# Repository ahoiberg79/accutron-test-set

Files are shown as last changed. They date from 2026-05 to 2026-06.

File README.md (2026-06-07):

# Accutron Test Set

Modern digital bench supply and current meter for Bulova Accutron tuning fork movements.

Designed for:

- voltage phasing
- low-amplitude testing
- current diagnostics
- general tuning fork movement evaluation

---

## Features

Adjustable low-voltage output with real-time voltage and microamp display.

Built around:

- Arduino Nano
- ADS1115 16-bit ADC
- SSD1306 OLED
- LM4040 precision reference

USB powered for bench use.

---

## Functions

### Adjustable Output Voltage

```text
0.00V → 2.50V
```

Common Accutron phasing voltages:

```text
1.05V
1.35V
1.55V
1.75V
1.80V
```

---

### Microamp Measurement

Current is measured through a 1k precision sense resistor using ADS1115 measurement across the sense resistor.

```text
A1 = sense high
A0 = sense low

Current = (A1 - A0) / 1000Ω
```

Displayed in real time on the OLED in microamps.

The measured current represents the current flowing through the connected watch movement, not the total current drawn by the tester circuitry.

---

### Actual Terminal Voltage Measurement

PCB V1.6 measures actual output terminal voltage directly at OUTPUT+ using ADS1115 channel A2.

```text
OUTPUT+ → ADS1115 A2
```

The displayed voltage is therefore the actual watch terminal voltage.

Firmware no longer applies software correction for the 470Ω output protection resistor.

Previous method:

```text
terminal voltage = set voltage - calculated 470Ω drop
```

Current PCB V1.6 method:

```text
terminal voltage = A2 voltage reading
```

---

## Hardware

### Main Components

```text
Arduino Nano
ADS1115 ADC Module
SSD1306 OLED Display
LM4040AIZ-2.5 precision reference
10-turn 10k potentiometer
SPST RUN/STOP switch
```

### Passive Components

```text
1k precision sense resistor
470Ω output protection resistor
100k switched-node pull-down resistor
2.2k LM4040 bias resistor
10µF capacitors
0.1µF capacitors
```

---

## Analog Measurement Path

```text
LM4040 2.5V reference
↓
10-turn 10k potentiometer
↓
RUN/STOP switch
↓
A1 / sense high
↓
1k current sense resistor
↓
A0 / sense low
↓
470Ω output protection resistor
↓
OUTPUT+
↓
watch movement
↓
GND
```

Voltage sense:

```text
OUTPUT+ → ADS1115 A2
```

---

## Switched-Node Pull-Down Resistor

PCB V1.6 includes a required 100kΩ pull-down resistor from the RUN/STOP switch output node to ground.

Connection:

```text
SW_OUT / ADS1115 A1 / high side of 1k current-sense resistor
↓
100kΩ
↓
GND
```

When the RUN/STOP switch is open, the switched output chain is otherwise floating:

```text
A1 → 1k sense resistor → A0 → 470Ω protection resistor → OUTPUT+ / ADS1115 A2
```

With no DC reference, this high-impedance node can retain charge or pick up leakage and capacitive coupling from the USB supply, wiring, ADS1115 inputs, display wiring, or nearby circuitry. This can cause false OFF-state voltage readings at OUTPUT+ / A2.

The 100kΩ pull-down provides a weak ground reference and discharge path for the switched node, forcing the output chain near 0V in STOP mode.

The resistor is intentionally placed at the switch output / A1 node, before the 1k current-sense resistor. Its current returns directly to ground and does not pass through the 1k sense resistor, so it is not included in the displayed watch-current measurement.

Do not place this resistor from OUTPUT+ to ground. A resistor at OUTPUT+ would draw current through the 1k sense resistor and would appear as false watch current.

Example:

```text
1.5V / 100kΩ = 15µA
```

If placed at OUTPUT+, that 15µA would be incorrectly displayed as watch current.

---

## Display Behavior

The OLED displays:

```text
terminal voltage
watch current in µA
```

During voltage adjustment, current display is temporarily blanked:

```text
--.- uA
```

After the voltage settles, the firmware discards transient readings and resumes displaying measured current.

This prevents stale or adjustment-related current readings from being shown as valid watch current.

---

## Notes

This is a bench-powered device intended for hobbyist restoration and diagnostic use.

The design is inspired by original Bulova test equipment but implemented using modern components and digital measurement.

The current display is intended to mimic the useful behavior of an analog microamp meter while preserving a true measured current value from the 1k sense resistor.

3D Printed Potentiometer Knob I used can be found here: https://makerworld.com/en/models/1847807-25mm-potentiometer-knob-mxr-fender-style-6-35mm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

3D Printed 0.96 OLED Panel Mount I used can be found here: https://www.printables.com/model/569276-ssd1306-adapter-for-enclosure-mounting/files

3D Printed enclosure I designed can be found here: https://makerworld.com/en/models/2901741-modern-accutron-test-set-enclosure#profileId-3243880

---

## Future Development

Possible future improvements:

```text
Larger OLED
Digital voltage presets
PCB version
Selectable movement profiles
High-current caution indicator
Kelvin terminal sensing
Rechargeable battery operation
Dedicated movement adapters
```

---

## Usage & Licensing

This project is shared for:

- personal use
- learning
- hobbyist restoration work

Please do not commercially reproduce or sell this design or derivative versions without permission from the project author.

Community improvements and technical collaboration are encouraged.

---

## Disclaimer

Use at your own risk when testing vintage electronic watch movements.

Always verify polarity and voltage before connecting a movement.

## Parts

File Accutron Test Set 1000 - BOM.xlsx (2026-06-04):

Category | Qty per unit | Item | Spec / Value | PCB Ref / Use | Buy / Track Notes | Vendor
PCB | 1 | Custom PCB | 2-layer FR-4 approx 80x60mm | Main board | Include PCB shipping divided by quantity | PCBWay
Controller | 1 | Arduino Nano V3 | ATmega328P USB-C preferred | U1 | Socketed | Amazon
ADC | 1 | ADS1115 module | 16-bit I2C ADC 1x10 header | U2 | Socketed | Amazon
Voltage Reference | 1 | LM4040AIZ-2.5/NOPB | 2.5V shunt reference TO-92 | U3 | LM4040BIZ also acceptable | Mouser
Potentiometer | 1 | 10-turn potentiometer | 10k linear panel mount solder lugs | RV1 | Voltage control | Jameco
Display | 1 | SSD1306 OLED module | 0.96 inch I2C 4-pin | DS1 | Panel mounted | Amazon
Switch | 1 | SPST rocker switch | ON/OFF panel mount | SW1 | RUN / STOP | Amazon
Output Jack | 1 | Red banana jack / binding post | 4mm panel mount | J1 | Output positive / SENSE_VOLTAGE | Amazon
Output Jack | 1 | Black banana jack / binding post | 4mm panel mount | J2 | Output negative / GND | Amazon
Test leads | 1 | Black/red banana & alligator clips | Found cheap ones on Jameco | J1 & J2 output | Plugs into J1 and J2 | Jameco
USB Power | 1 | Panel-mount USB-C extension | USB-C female panel / usb-c male | Nano USB input | Plugs into Nano USB-C | AliExpress
Resistor | 1 | Metal film resistor | 2.2k | R1 | LM4040 feed resistor | Amazon
Resistor | 1 | Precision metal film resistor | 1k 0.1% or 1% | R2 | Current sense resistor | Amazon
Resistor | 1 | Metal film resistor | 470R | R3 | Output protection resistor | Amazon
Resistor | 1 | Metal film resistor | 100k | R4 | Output pull-down resistor | Amazon
Capacitor | 2 | Electrolytic capacitor | 10uF radial | C1 C3 | Observe polarity | Amazon
Capacitor | 4 | Ceramic capacitor | 0.1uF | C2 C4 C5 C6 | Bypass capacitors | Amazon
Header Socket | 2 | Female header strip | 1x15 2.54mm | U1 socket | For Arduino Nano | Amazon
Header Socket | 1 | Female header strip | 1x10 2.54mm | U2 socket | For ADS1115 module | Amazon
Header / Connector | 1 | 4-pin header or connector | 2.54mm or JST | DS1 | OLED connection | Amazon
Header / Connector | 1 | 3-pin header or connector | 2.54mm or JST | RV1 | Pot connection | Amazon
Header / Connector | 1 | 2-pin header or connector | 2.54mm or JST | SW1 | Switch connection | Amazon
Wire Pad / Connector | 1 | 1-pin wire pad or header | Output positive | J1 | Wire to red banana jack | Amazon
Wire Pad / Connector | 1 | 1-pin wire pad or header | Output negative | J2 | Wire to black banana jack | Amazon
Knob | 1 | Potentiometer knob | Fits pot shaft | RV1 | Optional counting dial if desired | Jameco
Enclosure | 1 | 3D printed enclosure | Custom | Case | Include filament/resin cost | Local
PCB Holder | 1 | 3D printed PCB holder | M2 mounting pattern | Board holder | Include filament/resin cost | Local
Consumable | 1 | Wire/solder/heat shrink/nuts/screws | All inclusive | Assembly | All consumable parts | Local

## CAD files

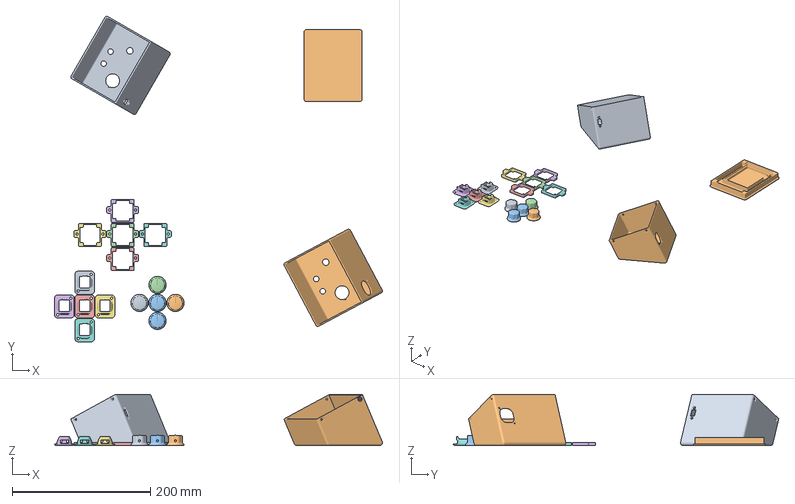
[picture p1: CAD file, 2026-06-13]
Full Accutron Test Set Print Parts.3mf
474.8 x 471.3 x 74.1 mm
Top
Base.stl
25mm MXR Knob T Lab v2.stl x 5
Printed XLR Keystone.step x 5
Top.stl

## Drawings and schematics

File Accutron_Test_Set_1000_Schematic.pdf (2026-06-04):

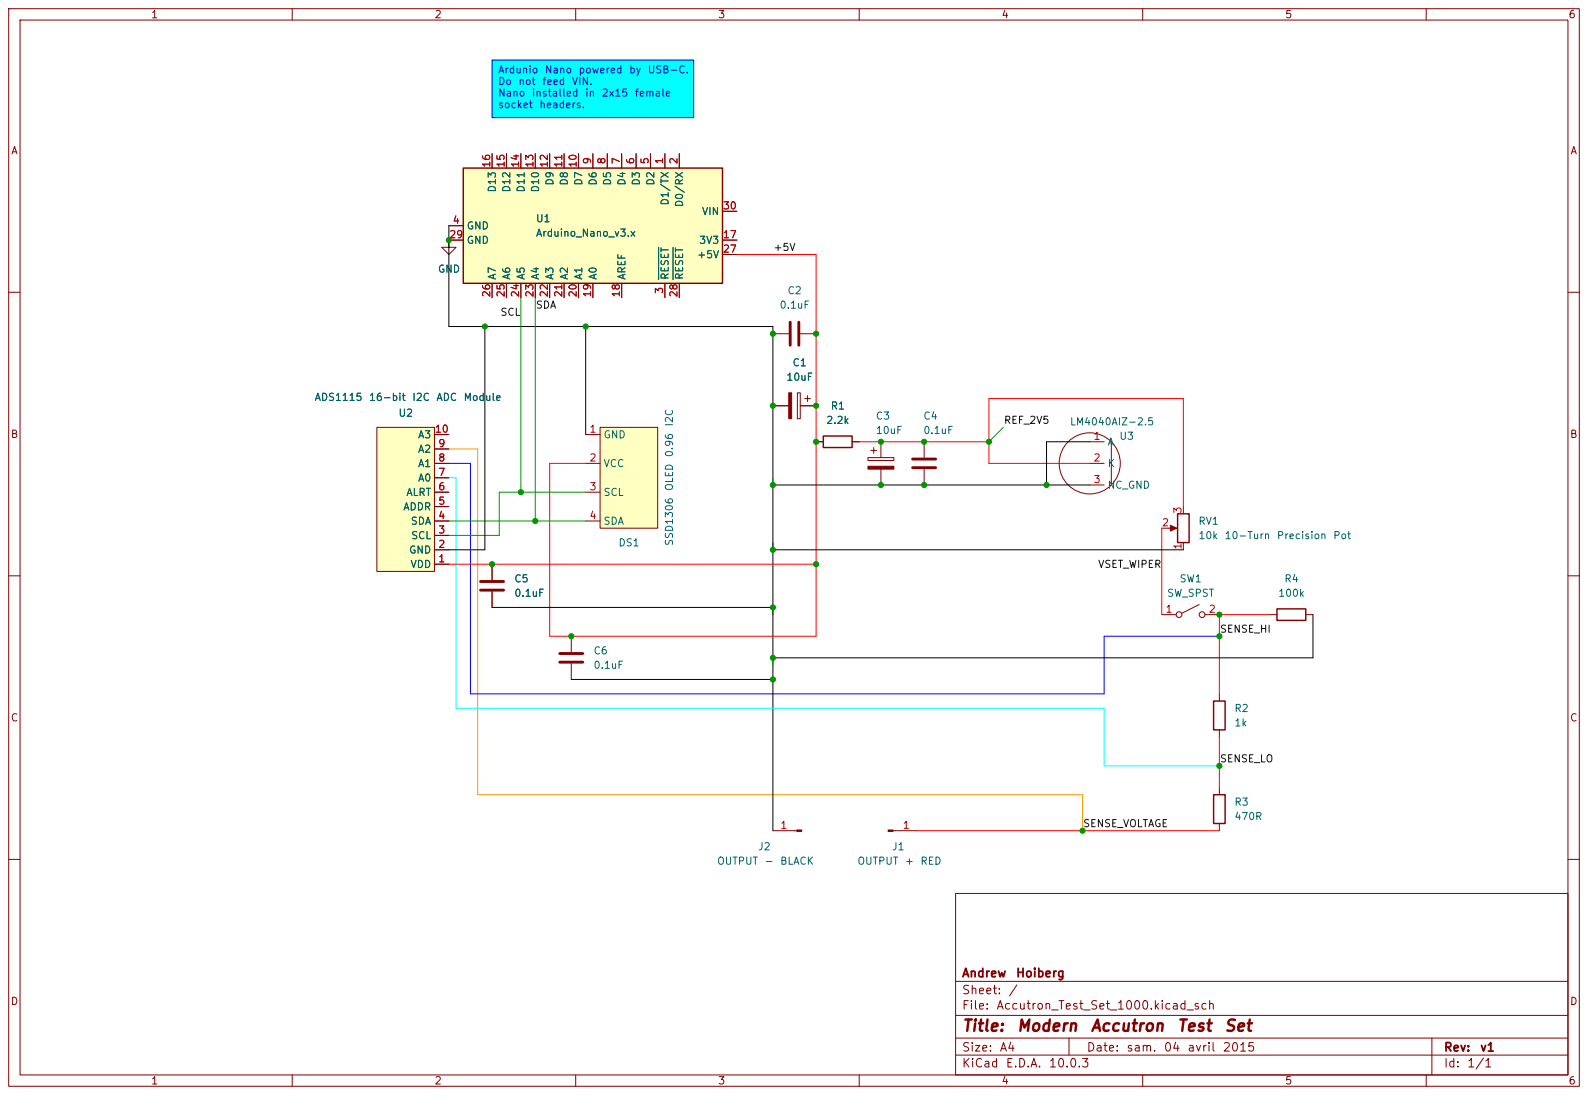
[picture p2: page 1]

Ardunio Nano powered by USB-C. Do not feed VIN. Nano installed in 2x15 female

Andrew Hoiberg
Sheet: /
File: Accutron_Test_Set_1000.kicad_sch
Title: Modern Accutron Test Set

Size: A4 | Rev: v1
KiCad E.D.A. 10.0.3 | Id: 1/1

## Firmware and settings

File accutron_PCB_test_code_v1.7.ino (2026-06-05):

#include <Wire.h>
#include <Adafruit_GFX.h>
#include <Adafruit_SSD1306.h>
#include <Adafruit_ADS1X15.h>

#define SCREEN_WIDTH 128
#define SCREEN_HEIGHT 64

Adafruit_SSD1306 display(SCREEN_WIDTH, SCREEN_HEIGHT, &Wire, -1);
Adafruit_ADS1115 ads;

// PCB V1.6 ADS1115 channel mapping
const uint8_t CH_SENSE_LO = 0;  // A0: after 1k sense resistor
const uint8_t CH_SENSE_HI = 1;  // A1: before 1k sense resistor
const uint8_t CH_OUTPUT   = 2;  // A2: actual output terminal voltage

// Hardware values
const float senseResistor_ohms = 1000.0;

// ADS1115 GAIN_ONE = +/-4.096V range = 0.125mV per count
const float ADS_VOLTS_PER_COUNT = 0.000125;

// -----------------------------
// Current measurement settings
// -----------------------------

// Paired A1/A0 samples per current block.
// Higher = more stable but slower response.
const int currentBlockSamples = 32;

// Current rolling average buffer.
// Higher = more analog-meter-like damping.
const int currentBufferSize = 8;

float currentBuffer[currentBufferSize];
int currentBufferIndex = 0;
int currentBufferCount = 0;

// Final display damping after rolling average.
// Lower = steadier/slower. Higher = faster/jumpier.
const float currentDisplaySmoothing = 0.12;

float displayedCurrent_uA = 0.0;
float filteredCurrent_uA = 0.0;

// Noise cleanup
const float zeroDeadband_uA = 0.35;

// If a single current block jumps this much, require persistence.
// This prevents one bad block from moving the display hard.
const float currentJumpThreshold_uA = 5.0;
const int requiredJumpPersistence = 3;
int jumpPersistenceCounter = 0;
float pendingJumpCurrent_uA = 0.0;

// Neutral caution flag only.
// Tester does not know movement type, so this should not be treated as pass/fail.
const float highCurrentThreshold_uA = 12.0;
const int highCurrentPersistenceBlocks = 4;
int highCurrentCounter = 0;
bool highCurrentFlag = false;

// -----------------------------
// Voltage / adjustment blanking
// -----------------------------

// Larger threshold prevents normal phasing drift from being treated as pot movement.
const float voltageMoveThreshold = 0.025;       // 25mV
const int voltageMoveConfirmCount = 3;          // require repeated movement
const unsigned long currentReacquire_ms = 500;  // blank after confirmed adjustment

// Below this, output is considered STOP/OFF.
// Current readings at near-zero output voltage are not meaningful.
const float outputOffThreshold_V = 0.10;

float previousVoltage = 0.0;
float stableVoltageReference = 0.0;
int voltageMoveCounter = 0;

unsigned long lastVoltageMove_ms = 0;
bool currentDisplayValid = false;

// -----------------------------
// Function declarations
// -----------------------------

float readOutputVoltage();
float readCurrentBlock_uA();
void resetCurrentFilter(float seedCurrent_uA);
void clearCurrentFilter();
float averageCurrentBuffer();
float processCurrentForDisplay(float rawCurrent_uA);
void updateHighCurrentFlag(float rawCurrent_uA);
void drawDisplay(float terminalVoltage, float current_uA, bool showCurrent);
void printDebug(float vOutput, float rawCurrent_uA, float filteredCurrent_uA, bool showCurrent);

// -----------------------------
// Setup
// -----------------------------

void setup() {
  Serial.begin(115200);

  if (!display.begin(SSD1306_SWITCHCAPVCC, 0x3C)) {
    while (true);
  }

  display.clearDisplay();
  display.setTextColor(SSD1306_WHITE);

  if (!ads.begin()) {
    display.setTextSize(1);
    display.setCursor(0, 0);
    display.println("ADS1115 FAIL");
    display.display();
    while (true);
  }

  ads.setGain(GAIN_ONE);

  stableVoltageReference = 0.0;
  previousVoltage = 0.0;
  lastVoltageMove_ms = millis();

  display.clearDisplay();
  display.display();
}

// -----------------------------
// Main loop
// -----------------------------

void loop() {
  // 1. Read actual output terminal voltage from A2.
  float terminalVoltage = readOutputVoltage();

  // 2. Treat very low output as STOP/OFF.
  bool outputOff = terminalVoltage < outputOffThreshold_V;

  if (outputOff) {
    // In STOP/OFF, current display is intentionally blanked.
    // Any current reading here is not useful watch-current information.
    lastVoltageMove_ms = millis();
    currentDisplayValid = false;
    clearCurrentFilter();

    stableVoltageReference = terminalVoltage;
    voltageMoveCounter = 0;
  } else {
    // 3. Detect deliberate voltage movement without reacting to small drift.
    float voltageChangeFromStable = fabs(terminalVoltage - stableVoltageReference);

    if (voltageChangeFromStable > voltageMoveThreshold) {
      voltageMoveCounter++;

      if (voltageMoveCounter >= voltageMoveConfirmCount) {
        lastVoltageMove_ms = millis();
        currentDisplayValid = false;
        clearCurrentFilter();

        // Set new baseline after confirmed movement.
        stableVoltageReference = terminalVoltage;
        voltageMoveCounter = 0;
      }
    } else {
      // Slowly track minor drift without declaring adjustment.
      stableVoltageReference =
        (stableVoltageReference * 0.95) + (terminalVoltage * 0.05);

      voltageMoveCounter = 0;
    }
  }

  previousVoltage = terminalVoltage;

  // 4. Always measure a fresh current block.
  //    It is only displayed/filtered when voltage is valid and stable.
  float rawCurrent_uA = readCurrentBlock_uA();

  // 5. Current display is allowed only after reacquire time and above OFF threshold.
  bool voltageRecentlyMoved =
    (millis() - lastVoltageMove_ms) < currentReacquire_ms;

  bool showCurrent = !voltageRecentlyMoved && !outputOff;

  if (!showCurrent) {
    currentDisplayValid = false;
    clearCurrentFilter();
  } else {
    if (!currentDisplayValid) {
      resetCurrentFilter(rawCurrent_uA);
      displayedCurrent_uA = rawCurrent_uA;
      filteredCurrent_uA = rawCurrent_uA;
      currentDisplayValid = true;
    } else {
      filteredCurrent_uA = processCurrentForDisplay(rawCurrent_uA);

      displayedCurrent_uA =
        (displayedCurrent_uA * (1.0 - currentDisplaySmoothing)) +
        (filteredCurrent_uA * currentDisplaySmoothing);
    }

    updateHighCurrentFlag(rawCurrent_uA);
  }

  drawDisplay(terminalVoltage, displayedCurrent_uA, showCurrent);
  printDebug(terminalVoltage, rawCurrent_uA, filteredCurrent_uA, showCurrent);

  delay(100);
}

// -----------------------------
// Read A2 output voltage
// -----------------------------

float readOutputVoltage() {
  // Dummy read after mux switch.
  // This helps avoid stale ADS1115 mux residue.
  ads.readADC_SingleEnded(CH_OUTPUT);
  delay(8);

  const int samples = 16;
  long sum = 0;

  for (int i = 0; i < samples; i++) {
    sum += ads.readADC_SingleEnded(CH_OUTPUT);
    delay(1);
  }

  float rawAverage = sum / (float)samples;
  float voltage = rawAverage * ADS_VOLTS_PER_COUNT;

  if (voltage < 0.0) {
    voltage = 0.0;
  }

  return voltage;
}

// -----------------------------
// Read true watch current
// -----------------------------

float readCurrentBlock_uA() {
  long sumHi = 0;
  long sumLo = 0;

  // Paired sampling:
  // A1, A0, A1, A0...
  for (int i = 0; i < currentBlockSamples; i++) {
    sumHi += ads.readADC_SingleEnded(CH_SENSE_HI);
    sumLo += ads.readADC_SingleEnded(CH_SENSE_LO);
    delay(1);
  }

  float vSenseHi = (sumHi / (float)currentBlockSamples) * ADS_VOLTS_PER_COUNT;
  float vSenseLo = (sumLo / (float)currentBlockSamples) * ADS_VOLTS_PER_COUNT;

  float current_uA =
    ((vSenseHi - vSenseLo) / senseResistor_ohms) * 1000000.0;

  // Clamp tiny ADC noise to zero.
  if (current_uA > -zeroDeadband_uA && current_uA < zeroDeadband_uA) {
    current_uA = 0.0;
  }

  // Reverse current is not meaningful for this tester display.
  if (current_uA < 0.0) {
    current_uA = 0.0;
  }

  return current_uA;
}

// -----------------------------
// Current filter reset / clear
// -----------------------------

void resetCurrentFilter(float seedCurrent_uA) {
  currentBufferIndex = 0;
  currentBufferCount = currentBufferSize;

  for (int i = 0; i < currentBufferSize; i++) {
    currentBuffer[i] = seedCurrent_uA;
  }

  filteredCurrent_uA = seedCurrent_uA;
  displayedCurrent_uA = seedCurrent_uA;

  jumpPersistenceCounter = 0;
  pendingJumpCurrent_uA = seedCurrent_uA;

  highCurrentCounter = 0;
  highCurrentFlag = false;
}

void clearCurrentFilter() {
  currentBufferIndex = 0;
  currentBufferCount = 0;

  filteredCurrent_uA = 0.0;
  displayedCurrent_uA = 0.0;

  jumpPersistenceCounter = 0;
  pendingJumpCurrent_uA = 0.0;

  highCurrentCounter = 0;
  highCurrentFlag = false;
}

// -----------------------------
// Rolling average
// -----------------------------

float averageCurrentBuffer() {
  if (currentBufferCount <= 0) {
    return 0.0;
  }

  float sum = 0.0;

  for (int i = 0; i < currentBufferCount; i++) {
    sum += currentBuffer[i];
  }

  return sum / (float)currentBufferCount;
}

// -----------------------------
// Current processing
// -----------------------------

float processCurrentForDisplay(float rawCurrent_uA) {
  float currentAverageBefore = averageCurrentBuffer();
  float delta = fabs(rawCurrent_uA - currentAverageBefore);

  bool largeJump = delta > currentJumpThreshold_uA;

  if (largeJump) {
    // A real current change will persist.
    // A one-block spike is ignored.
    if (jumpPersistenceCounter == 0) {
      pendingJumpCurrent_uA = rawCurrent_uA;
      jumpPersistenceCounter = 1;
      return currentAverageBefore;
    }

    if (fabs(rawCurrent_uA - pendingJumpCurrent_uA) <= currentJumpThreshold_uA) {
      jumpPersistenceCounter++;
    } else {
      pendingJumpCurrent_uA = rawCurrent_uA;
      jumpPersistenceCounter = 1;
      return currentAverageBefore;
    }

    if (jumpPersistenceCounter < requiredJumpPersistence) {
      return currentAverageBefore;
    }

    // Persistent jump accepted.
    jumpPersistenceCounter = 0;
  } else {
    jumpPersistenceCounter = 0;
  }

  currentBuffer[currentBufferIndex] = rawCurrent_uA;
  currentBufferIndex++;

  if (currentBufferIndex >= currentBufferSize) {
    currentBufferIndex = 0;
  }

  if (currentBufferCount < currentBufferSize) {
    currentBufferCount++;
  }

  return averageCurrentBuffer();
}

// -----------------------------
// High-current caution flag
// -----------------------------

void updateHighCurrentFlag(float rawCurrent_uA) {
  if (rawCurrent_uA > highCurrentThreshold_uA) {
    highCurrentCounter++;

    if (highCurrentCounter >= highCurrentPersistenceBlocks) {
      highCurrentFlag = true;
    }
  } else {
    highCurrentCounter = 0;
    highCurrentFlag = false;
  }
}

// -----------------------------
// OLED display
// -----------------------------

void drawDisplay(float terminalVoltage, float current_uA, bool showCurrent) {
  char voltageText[8];
  char currentText[8];

  dtostrf(terminalVoltage, 5, 2, voltageText);
  dtostrf(current_uA, 4, 1, currentText);

  display.clearDisplay();
  display.setTextColor(SSD1306_WHITE);

  display.setTextSize(3);

  // Voltage
  display.setCursor(3, 11);
  display.print(voltageText);

  display.setCursor(104, 11);
  display.print("V");

  // Current
  display.setCursor(4, 39);

  if (!showCurrent) {
    display.print("--.-");
  } else {
    display.print(currentText);
  }

  display.setCursor(88, 39);
  display.print("uA");

  // Optional neutral high-current caution marker.
  // Tester does not know movement type, so use "HI?" only as a caution.
  if (showCurrent && highCurrentFlag) {
    display.setTextSize(1);
    display.setCursor(109, 56);
    display.print("HI?");
  }

  display.display();
}

// -----------------------------
// Serial debug
// -----------------------------

void printDebug(float vOutput, float rawCurrent_uA, float filteredCurrent_uA, bool showCurrent) {
  Serial.print("A2=");
  Serial.print(vOutput, 4);

  Serial.print(" V  RAW=");
  Serial.print(rawCurrent_uA, 2);

  Serial.print(" uA  FILT=");
  Serial.print(filteredCurrent_uA, 2);

  Serial.print(" uA  DISP=");
  Serial.print(displayedCurrent_uA, 2);

  Serial.print(" uA  SHOW=");
  Serial.print(showCurrent ? "YES" : "NO");

  Serial.print("  HI?=");
  Serial.println(highCurrentFlag ? "YES" : "NO");
}

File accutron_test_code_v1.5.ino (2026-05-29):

#include <Wire.h>
#include <Adafruit_GFX.h>
#include <Adafruit_SSD1306.h>
#include <Adafruit_ADS1X15.h>

#define SCREEN_WIDTH 128
#define SCREEN_HEIGHT 64

Adafruit_SSD1306 display(SCREEN_WIDTH, SCREEN_HEIGHT, &Wire, -1);
Adafruit_ADS1115 ads;

const float senseResistor = 1000.0;
const float protectionResistor = 470.0;

const float zeroDeadband_uA = 3.0;

// Detect voltage adjustment
const float voltageMoveThreshold = 0.006;
const int blankLoopsAfterMove = 3;

float previousVoltage = 0.0;
int blankCounter = 0;

void readAveragedPair(float &vA1, float &vA0) {
  long sumA1 = 0;
  long sumA0 = 0;

  const int samples = 50;

  for (int i = 0; i < samples; i++) {
    sumA1 += ads.readADC_SingleEnded(1);
    sumA0 += ads.readADC_SingleEnded(0);
    delay(1);
  }

  vA1 = (sumA1 / (float)samples) * 0.000125;
  vA0 = (sumA0 / (float)samples) * 0.000125;
}

void setup() {
  Serial.begin(115200);

  if (!display.begin(SSD1306_SWITCHCAPVCC, 0x3C)) {
    while (true);
  }

  display.clearDisplay();
  display.setTextColor(SSD1306_WHITE);

  if (!ads.begin()) {
    display.setTextSize(1);
    display.setCursor(0, 0);
    display.println("ADS1115 FAIL");
    display.display();
    while (true);
  }

  ads.setGain(GAIN_ONE);

  display.clearDisplay();
  display.display();
}

void loop() {
  float vA1, vA0;
  readAveragedPair(vA1, vA0);

  float current_uA = ((vA1 - vA0) / senseResistor) * 1000000.0;

  if (current_uA < zeroDeadband_uA && current_uA > -zeroDeadband_uA) {
    current_uA = 0.0;
  }

  if (current_uA < 0.0) {
    current_uA = 0.0;
  }

  float terminalVoltage =
      vA0 - ((current_uA / 1000000.0) * protectionResistor);

  if (terminalVoltage < 0.0) {
    terminalVoltage = 0.0;
  }

  float voltageChange = abs(terminalVoltage - previousVoltage);

  if (voltageChange > voltageMoveThreshold) {
    blankCounter = blankLoopsAfterMove;
    current_uA = 0.0;   // discard transient calculation
  } else if (blankCounter > 0) {
    blankCounter--;
    current_uA = 0.0;   // keep blanking while settling
  }

  previousVoltage = terminalVoltage;

  char voltageText[8];
  char currentText[8];

  dtostrf(terminalVoltage, 5, 2, voltageText);
  dtostrf(current_uA, 4, 1, currentText);

  display.clearDisplay();
  display.setTextSize(3);

  display.setCursor(3, 11);
  display.print(voltageText);

  display.setCursor(104, 11);
  display.print("V");

  display.setCursor(4, 39);

  if (blankCounter > 0) {
    display.print("--.-");
  } else {
    display.print(currentText);
  }

  display.setCursor(88, 39);
  display.print("uA");

  display.display();

  delay(100);
}

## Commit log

2026-05-26 Add files via upload
    Updated code on Arduino file to calculate correct voltage at terminal, accounting for voltage loss over 470 resistor.
    [accutron_test_code_v1.5.ino]
2026-05-29 Voltage/current readings and display logic
2026-05-29 Adjust cursor position for voltage display & voltage/uA reading refresh
2026-05-29 Aligned decimal point & smoothed voltage / current display measurements
2026-06-04 Updated Schematic from KiCAD
2026-06-04 Updated BOM
    [Accutron Test Set 1000 - BOM.xlsx]
2026-06-04 Code for PCB with A2 output sense added
2026-06-04 Code for PCB with added A2 node to sense true voltage
    NOTE: A 100k pull-down resistor needs to be connected from the switch output to GND in order to drain the ghost/leftover voltage from the output to bring down to 0V so no power will get to the moveme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
2026-06-04 Updated with pull-down resistor addition info to PCB
2026-06-04 Updated with 100k pull-down resistor at SENSE_HI
    This resistor is needed to ensure voltage is near or at 0 when switch is in 'STOP' position.
2026-06-04 Updated with addition of 100k pull-down resistor
    [Accutron Test Set 1000 - BOM.xlsx]
2026-06-05 Refactor current detection thresholds and filtering
    Updated high current threshold and voltage move threshold for improved detection. Added clearCurrentFilter function to reset current readings more effectively.
    [accutron_PCB_test_code_v1.7.ino]
2026-06-06 Update README with links to 3D printed parts
    Added links to 3D printed components used in the project.
2026-06-07 Update link for 3D printed enclosure design
2026-06-13 Accutron Test Set - Full 3D Print Parts
    [Full Accutron Test Set Print Parts.3mf]
